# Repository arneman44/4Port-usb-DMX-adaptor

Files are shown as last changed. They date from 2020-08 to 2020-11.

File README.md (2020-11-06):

4Port usb DMX adaptor

As a beginning lighting tech at my local youth club. I needed a cheap way to control some lighting fixtures via DMX. That's why I created this USB-DMX dongle that's open-source so my fellow DIYers can build one themself. I will be selling these as PCB's, kits, and assembled units. At what I find a very reasonable price.

More info can be found on: https://nortle.be/15-diy-4-port-usb-dmx/

i used JCLPCB for ordering pcb's:
https://jlcpcb.com/

<p xmlns:dct="http://purl.org/dc/terms/" xmlns:cc="http://creativecommons.org/ns#" class="license-text"><span rel="dct:title">4 Port USB to DMX adaptor</span> by <a rel="cc:attributionURL dct:creator" property="cc:attributionName" href="www.nortle.be">Arne Van den Broeck</a> is licensed under <a rel="license" href="https://creativecommons.org/licenses/by-nc-sa/4.0">CC BY-NC-SA 4.0</a></p>

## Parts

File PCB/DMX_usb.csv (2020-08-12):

Source: | Y:\Projects\15_PC_DMX_USB_4port\4Port usb DMX adaptor\PCB\DMX_usb.sch
Date: | 5/08/2020 21:19:08
Tool: | Eeschema (5.1.4)-1
Component Count: | 80
Ref | Value | Footprint | Datasheet | Manufacturer | Vendor
C1 | 10uf | Capacitor_SMD:C_0805_2012Metric_Pad1.15x1.40mm_HandSolder | ~
C2 | 10uf | Capacitor_SMD:C_0805_2012Metric_Pad1.15x1.40mm_HandSolder | ~
C3 | 100nf | Capacitor_SMD:C_0805_2012Metric_Pad1.15x1.40mm_HandSolder | ~
C4 | 10uf | Capacitor_SMD:C_0805_2012Metric_Pad1.15x1.40mm_HandSolder | ~
C5 | 4.7uF | Capacitor_SMD:CP_Elec_4x5.4 | ~
C6 | 100nf | Capacitor_SMD:C_0805_2012Metric_Pad1.15x1.40mm_HandSolder | ~
C7 | 100nf | Capacitor_SMD:C_0805_2012Metric_Pad1.15x1.40mm_HandSolder | ~
C8 | 100nf | Capacitor_SMD:C_0805_2012Metric_Pad1.15x1.40mm_HandSolder | ~
C9 | 100nf | Capacitor_SMD:C_0805_2012Metric_Pad1.15x1.40mm_HandSolder | ~
C10 | 4.7uF | Capacitor_SMD:CP_Elec_4x5.4 | ~
C11 | 4.7uF | Capacitor_SMD:CP_Elec_4x5.4 | ~
C12 | 4.7uF | Capacitor_SMD:CP_Elec_4x5.4 | ~
C13 | 100nf | Capacitor_SMD:C_0805_2012Metric_Pad1.15x1.40mm_HandSolder | ~
C14 | 100nf | Capacitor_SMD:C_0805_2012Metric_Pad1.15x1.40mm_HandSolder | ~
C15 | 100nf | Capacitor_SMD:C_0805_2012Metric_Pad1.15x1.40mm_HandSolder | ~
C16 | 10nf | Capacitor_SMD:C_0805_2012Metric_Pad1.15x1.40mm_HandSolder | ~
C17 | 10nf | Capacitor_SMD:C_0805_2012Metric_Pad1.15x1.40mm_HandSolder | ~
C18 | 10nf | Capacitor_SMD:C_0805_2012Metric_Pad1.15x1.40mm_HandSolder | ~
C19 | 10nf | Capacitor_SMD:C_0805_2012Metric_Pad1.15x1.40mm_HandSolder | ~
C20 | 100nf | Capacitor_SMD:C_0805_2012Metric_Pad1.15x1.40mm_HandSolder | ~
C21 | 100nf | Capacitor_SMD:C_0805_2012Metric_Pad1.15x1.40mm_HandSolder | ~
C22 | 100nf | Capacitor_SMD:C_0805_2012Metric_Pad1.15x1.40mm_HandSolder | ~
C23 | 100nf | Capacitor_SMD:C_0805_2012Metric_Pad1.15x1.40mm_HandSolder | ~
C24 | 100nf | Capacitor_SMD:C_0805_2012Metric_Pad1.15x1.40mm_HandSolder | ~
D1 | LED | LED_SMD:LED_0805_2012Metric_Pad1.15x1.40mm_HandSolder | ~
D2 | LED | LED_SMD:LED_0805_2012Metric_Pad1.15x1.40mm_HandSolder | ~
D3 | LED | LED_SMD:LED_0805_2012Metric_Pad1.15x1.40mm_HandSolder | ~
D4 | LED | LED_SMD:LED_0805_2012Metric_Pad1.15x1.40mm_HandSolder | ~
D5 | LED | LED_SMD:LED_0805_2012Metric_Pad1.15x1.40mm_HandSolder | ~
D6 | LED | LED_SMD:LED_0805_2012Metric_Pad1.15x1.40mm_HandSolder | ~
D7 | LED | LED_SMD:LED_0805_2012Metric_Pad1.15x1.40mm_HandSolder | ~
D8 | LED | LED_SMD:LED_0805_2012Metric_Pad1.15x1.40mm_HandSolder | ~
F1 | Polyfuse | Fuse:Fuse_1206_3216Metric_Pad1.42x1.75mm_HandSolder | ~
F2 | Polyfuse | Fuse:Fuse_1206_3216Metric_Pad1.42x1.75mm_HandSolder | ~
F3 | Polyfuse | Fuse:Fuse_1206_3216Metric_Pad1.42x1.75mm_HandSolder | ~
F4 | Polyfuse | Fuse:Fuse_1206_3216Metric_Pad1.42x1.75mm_HandSolder | ~
IC1 | FE1.1S | SamacSys_Parts:SOP64P600X175-28N | https://cdn-shop.adafruit.com/product-files/2991/FE1.1s+Data+Sheet+(Rev.+1.0).pdf
J3 | XLR3 | Connector_Audio:Jack_XLR_Neutrik_NC3FAH1_Horizontal | ~
J4 | XLR3 | Connector_Audio:Jack_XLR_Neutrik_NC3FAH1_Horizontal | ~
J5 | XLR3 | Connector_Audio:Jack_XLR_Neutrik_NC3FAH1_Horizontal | ~
J6 | XLR3 | Connector_Audio:Jack_XLR_Neutrik_NC3FAH1_Horizontal | ~
J9 | Conn_01x03 | Connector_PinSocket_2.54mm:PinSocket_1x03_P2.54mm_Vertical | ~
J10 | Conn_01x03 | Connector_PinSocket_2.54mm:PinSocket_1x03_P2.54mm_Vertical | ~
J11 | Conn_01x03 | Connector_PinSocket_2.54mm:PinSocket_1x03_P2.54mm_Vertical | ~
J12 | Conn_01x03 | Connector_PinSocket_2.54mm:PinSocket_1x03_P2.54mm_Vertical | ~
J13 | USB_C_Receptacle_USB2.0 | Connector_USB:USB_C_Receptacle_Palconn_UTC16-G | https://www.usb.org/sites/default/files/documents/usb_type-c.zip
J14 | USB_C_Receptacle_USB2.0 | Connector_USB:USB_C_Receptacle_Palconn_UTC16-G | https://www.usb.org/sites/default/files/documents/usb_type-c.zip
J15 | USB_C_Receptacle_USB2.0 | Connector_USB:USB_C_Receptacle_Palconn_UTC16-G | https://www.usb.org/sites/default/files/documents/usb_type-c.zip
J16 | USB_C_Receptacle_USB2.0 | Connector_USB:USB_C_Receptacle_Palconn_UTC16-G | https://www.usb.org/sites/default/files/documents/usb_type-c.zip
J17 | Conn_01x04 | Connector_PinSocket_2.54mm:PinSocket_1x04_P2.54mm_Vertical | ~
R1 | 2.7K | Capacitor_SMD:C_0805_2012Metric_Pad1.15x1.40mm_HandSolder | ~
R2 | R | Resistor_SMD:R_0805_2012Metric_Pad1.15x1.40mm_HandSolder | ~
R3 | 560 | Capacitor_SMD:C_0805_2012Metric_Pad1.15x1.40mm_HandSolder | ~
R4 | 130 | Capacitor_SMD:C_0805_2012Metric_Pad1.15x1.40mm_HandSolder | ~
R5 | 560 | Capacitor_SMD:C_0805_2012Metric_Pad1.15x1.40mm_HandSolder | ~
R6 | R | Resistor_SMD:R_0805_2012Metric_Pad1.15x1.40mm_HandSolder | ~
R7 | R | Resistor_SMD:R_0805_2012Metric_Pad1.15x1.40mm_HandSolder | ~
R8 | R | Resistor_SMD:R_0805_2012Metric_Pad1.15x1.40mm_HandSolder | ~
R9 | 560 | Capacitor_SMD:C_0805_2012Metric_Pad1.15x1.40mm_HandSolder | ~
R10 | 130 | Capacitor_SMD:C_0805_2012Metric_Pad1.15x1.40mm_HandSolder | ~
R11 | 560 | Capacitor_SMD:C_0805_2012Metric_Pad1.15x1.40mm_HandSolder | ~
R12 | 560 | Capacitor_SMD:C_0805_2012Metric_Pad1.15x1.40mm_HandSolder | ~
R13 | 130 | Capacitor_SMD:C_0805_2012Metric_Pad1.15x1.40mm_HandSolder | ~
R14 | 560 | Capacitor_SMD:C_0805_2012Metric_Pad1.15x1.40mm_HandSolder | ~
R15 | 560 | Capacitor_SMD:C_0805_2012Metric_Pad1.15x1.40mm_HandSolder | ~
R16 | 130 | Capacitor_SMD:C_0805_2012Metric_Pad1.15x1.40mm_HandSolder | ~
R17 | 560 | Capacitor_SMD:C_0805_2012Metric_Pad1.15x1.40mm_HandSolder | ~
R18 | R | Resistor_SMD:R_0805_2012Metric_Pad1.15x1.40mm_HandSolder | ~
R19 | R | Resistor_SMD:R_0805_2012Metric_Pad1.15x1.40mm_HandSolder | ~
R20 | R | Resistor_SMD:R_0805_2012Metric_Pad1.15x1.40mm_HandSolder | ~
R21 | R | Resistor_SMD:R_0805_2012Metric_Pad1.15x1.40mm_HandSolder | ~
U1 | FT232RL | Package_SO:SSOP-28_5.3x10.2mm_P0.65mm | https://www.ftdichip.com/Support/Documents/DataSheets/ICs/DS_FT232R.pdf
U2 | 75176B | Package_SO:SOIC-8_3.9x4.9mm_P1.27mm
U3 | FT232RL | Package_SO:SSOP-28_5.3x10.2mm_P0.65mm | https://www.ftdichip.com/Support/Documents/DataSheets/ICs/DS_FT232R.pdf
U4 | FT232RL | Package_SO:SSOP-28_5.3x10.2mm_P0.65mm | https://www.ftdichip.com/Support/Documents/DataSheets/ICs/DS_FT232R.pdf
U5 | FT232RL | Package_SO:SSOP-28_5.3x10.2mm_P0.65mm | https://www.ftdichip.com/Support/Documents/DataSheets/ICs/DS_FT232R.pdf
U6 | 75176B | Package_SO:SOIC-8_3.9x4.9mm_P1.27mm
U7 | 75176B | Package_SO:SOIC-8_3.9x4.9mm_P1.27mm
U8 | 75176B | Package_SO:SOIC-8_3.9x4.9mm_P1.27mm
Y1 | Crystal 12MHZ | Crystal:Crystal_SMD_HC49-SD | ~

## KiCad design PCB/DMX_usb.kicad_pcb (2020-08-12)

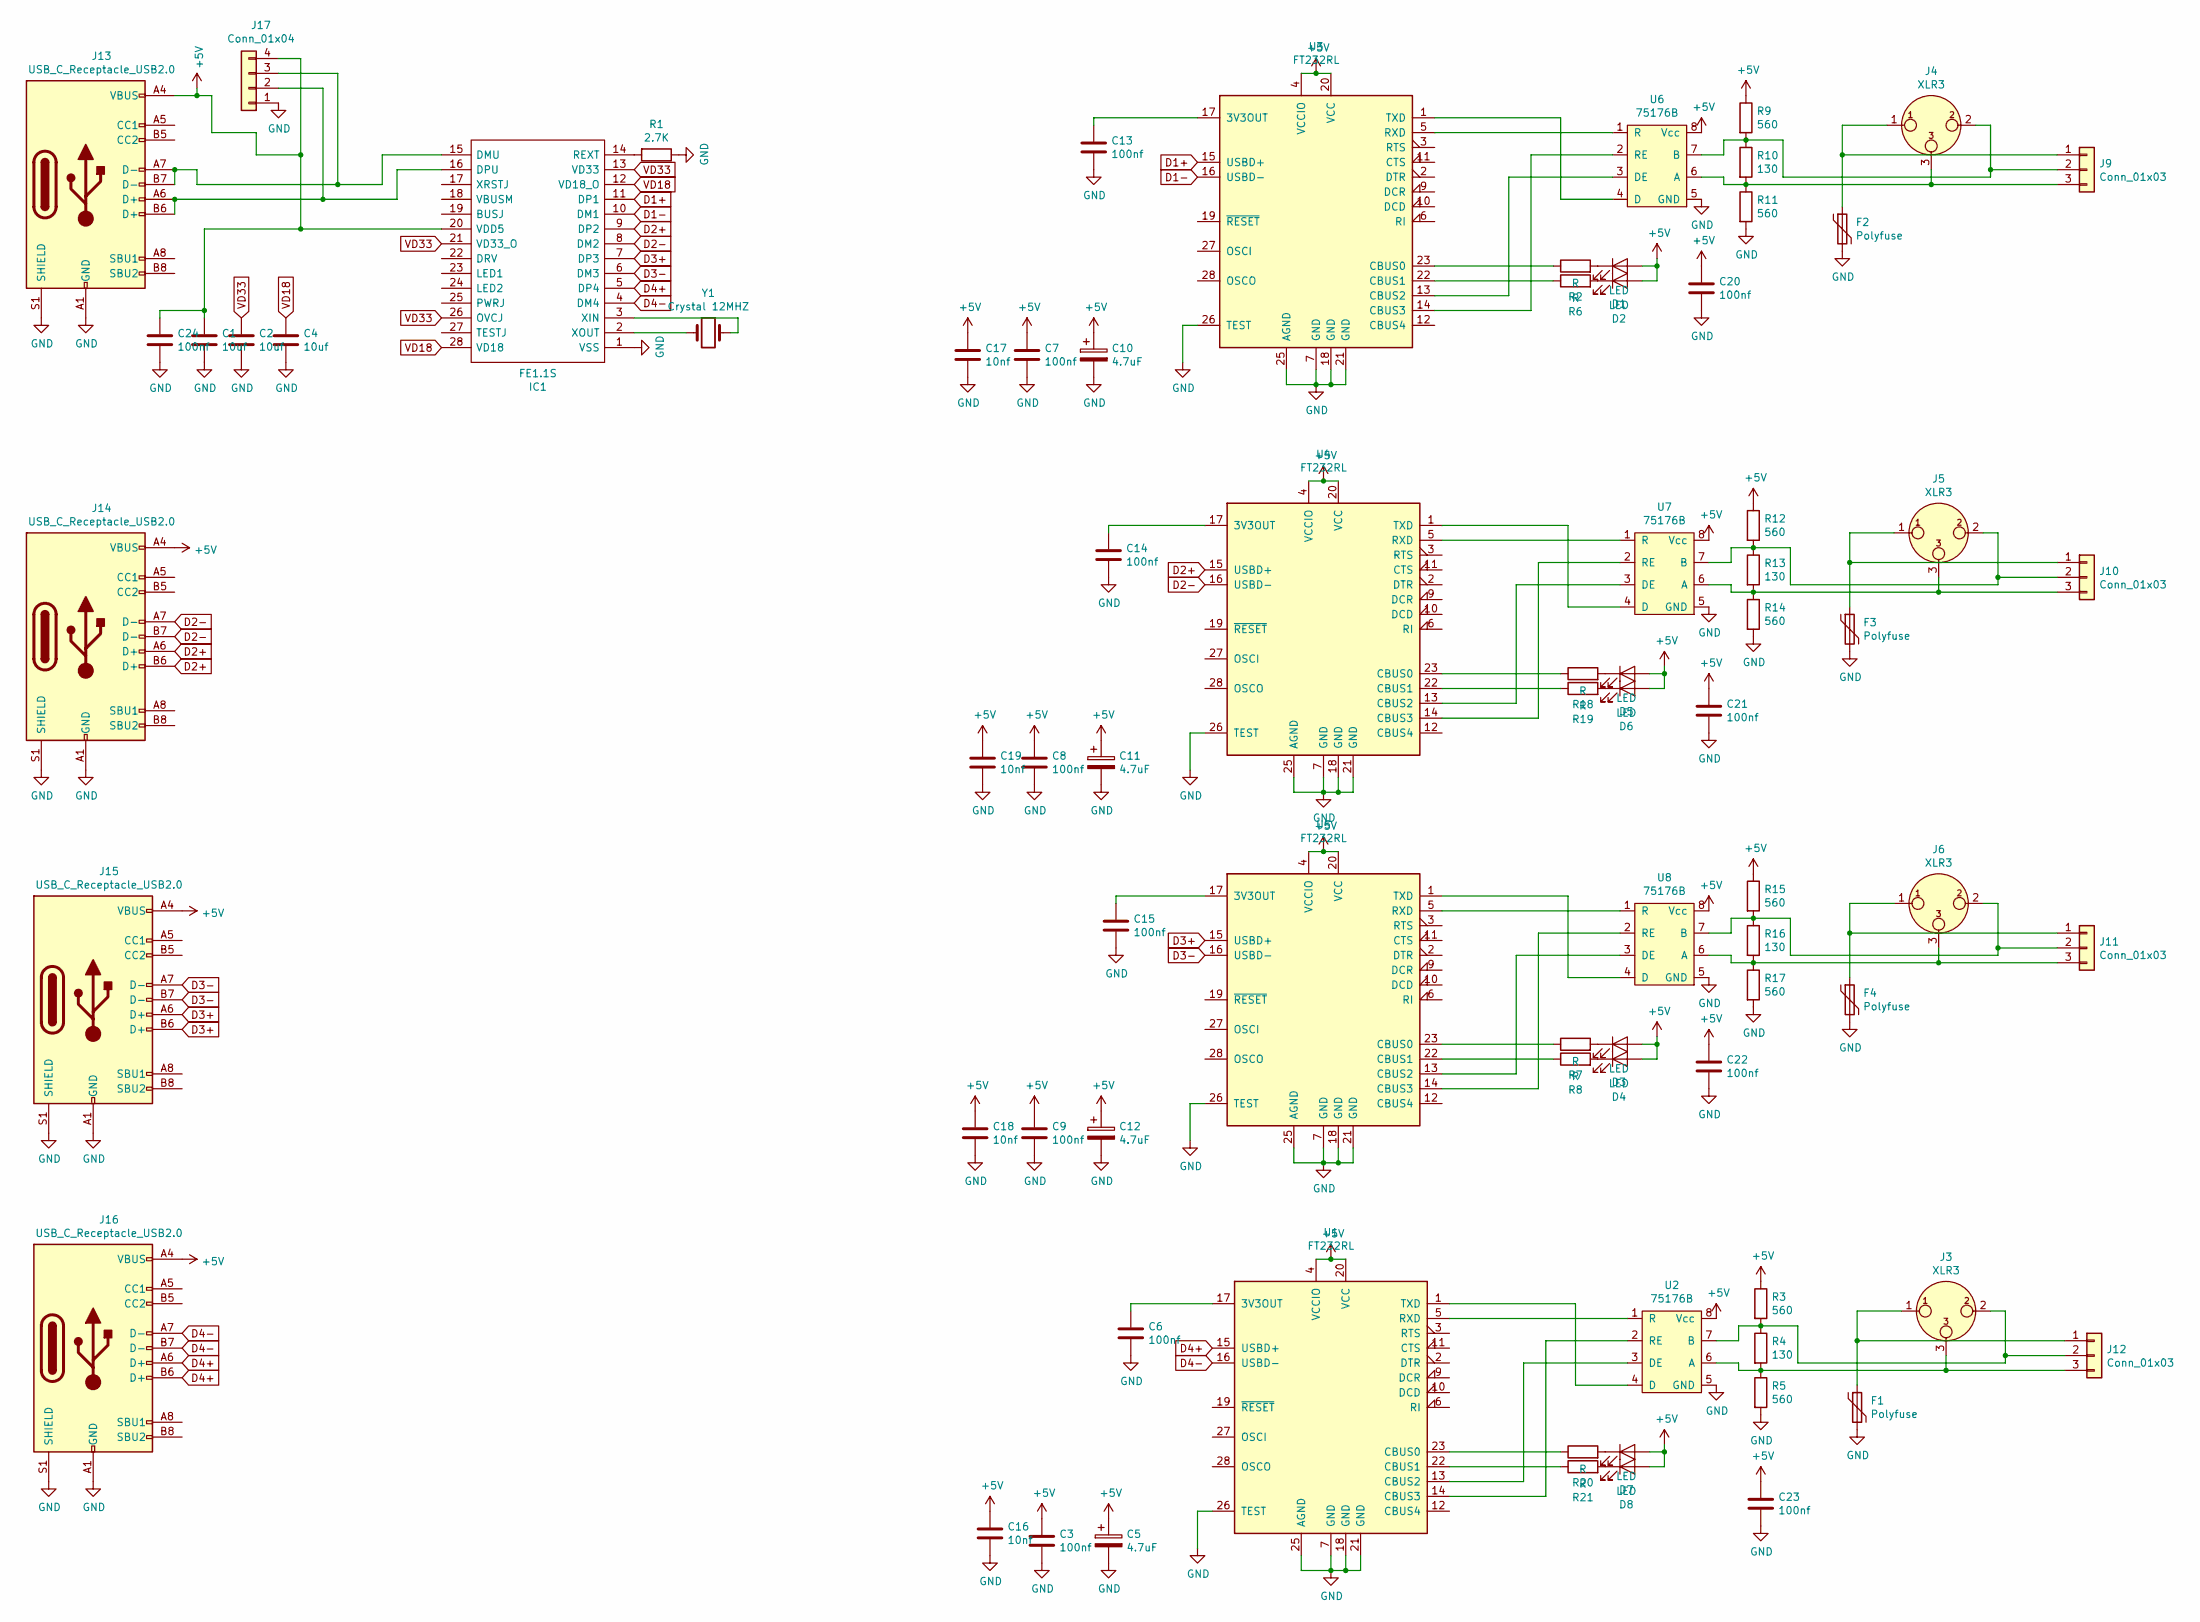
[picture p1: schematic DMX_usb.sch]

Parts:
C1, C2, C4: 10uf; C_0805_2012Metric_Pad1.15x1.40mm_HandSolder
C3, C6, C7, C8, C9, C13, C14, C15, C20, C21, C22, C23, C24: 100nf; C_0805_2012Metric_Pad1.15x1.40mm_HandSolder
C5, C10, C11, C12: 4.7uF; CP_Elec_4x5.4
C16, C17, C18, C19: 10nf; C_0805_2012Metric_Pad1.15x1.40mm_HandSolder
D1, D2, D3, D4, D5, D6, D7, D8: LED; LED_0805_2012Metric_Pad1.15x1.40mm_HandSolder
F1, F2, F3, F4: Polyfuse; Fuse_1206_3216Metric_Pad1.42x1.75mm_HandSolder
IC1: FE1.1S; SOP64P600X175-28N; Manufacturer_Part_Number FE1.1S
J3, J4, J5, J6: XLR3; Jack_XLR_Neutrik_NC3FAH1_Horizontal
J9, J10, J11, J12: Conn_01x03; PinSocket_1x03_P2.54mm_Vertical
J13, J14, J15, J16: USB_C_Receptacle_USB2.0; USB_C_Receptacle_Palconn_UTC16-G
J17: Conn_01x04; PinSocket_1x04_P2.54mm_Vertical
R1: 2.7K; C_0805_2012Metric_Pad1.15x1.40mm_HandSolder
R2, R6, R7, R8, R18, R19, R20, R21: R; R_0805_2012Metric_Pad1.15x1.40mm_HandSolder
R3, R5, R9, R11, R12, R14, R15, R17: 560; C_0805_2012Metric_Pad1.15x1.40mm_HandSolder
R4, R10, R13, R16: 130; C_0805_2012Metric_Pad1.15x1.40mm_HandSolder
U1, U3, U4, U5: FT232RL; SSOP-28_5.3x10.2mm_P0.65mm
U2, U6, U7, U8: 75176B; SOIC-8_3.9x4.9mm_P1.27mm
Y1: Crystal 12MHZ; Crystal_SMD_HC49-SD

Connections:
+5V: C1.1, C3.1, C5.1, C7.1, C8.1, C9.1, C10.1, C11.1, C12.1, C16.1, C17.1, C18.1, C19.1, C20.1, C21.1, C22.1, C23.1, C24.1, D1.2 (A), D2.2 (A), D3.2 (A), D4.2 (A), D5.2 (A), D6.2 (A), D7.2 (A), D8.2 (A), IC1.20 (VDD5), J13.A4 (VBUS), J13.A9 (VBUS), J13.B4 (VBUS), J13.B9 (VBUS), J14.A4 (VBUS), J14.A9 (VBUS), J14.B4 (VBUS), J14.B9 (VBUS), J15.A4 (VBUS), J15.A9 (VBUS), J15.B4 (VBUS), J15.B9 (VBUS), J16.A4 (VBUS), J16.A9 (VBUS), J16.B4 (VBUS), J16.B9 (VBUS), J17.4, R3.1, R9.1, R12.1, R15.1, U1.4 (VCCIO), U1.20 (VCC), U2.8 (Vcc), U3.4 (VCCIO), U3.20 (VCC), U4.4 (VCCIO), U4.20 (VCC), U5.4 (VCCIO), U5.20 (VCC), U6.8 (Vcc), U7.8 (Vcc), U8.8 (Vcc)
D1+: IC1.11 (DP1), U3.15 (USBD+)
D1-: IC1.10 (DM1), U3.16 (USBD-)
D2+: IC1.9 (DP2), J14.A6 (D+), J14.B6 (D+), U4.15 (USBD+)
D2-: IC1.8 (DM2), J14.A7 (D-), J14.B7 (D-), U4.16 (USBD-)
D3+: IC1.7 (DP3), J15.A6 (D+), J15.B6 (D+), U5.15 (USBD+)
D3-: IC1.6 (DM3), J15.A7 (D-), J15.B7 (D-), U5.16 (USBD-)
D4+: IC1.5 (DP4), J16.A6 (D+), J16.B6 (D+), U1.15 (USBD+)
D4-: IC1.4 (DM4), J16.A7 (D-), J16.B7 (D-), U1.16 (USBD-)
GND: C1.2, C2.2, C3.2, C4.2, C5.2, C6.2, C7.2, C8.2, C9.2, C10.2, C11.2, C12.2, C13.2, C14.2, C15.2, C16.2, C17.2, C18.2, C19.2, C20.2, C21.2, C22.2, C23.2, C24.2, F1.2, F2.2, F3.2, F4.2, IC1.1 (VSS), J13.A1 (GND), J13.A12 (GND), J13.B1 (GND), J13.B12 (GND), J13.S1 (SHIELD), J14.A1 (GND), J14.A12 (GND), J14.B1 (GND), J14.B12 (GND), J14.S1 (SHIELD), J15.A1 (GND), J15.A12 (GND), J15.B1 (GND), J15.B12 (GND), J15.S1 (SHIELD), J16.A1 (GND), J16.A12 (GND), J16.B1 (GND), J16.B12 (GND), J16.S1 (SHIELD), J17.1, R1.1, R5.2, R11.2, R14.2, R17.2, U1.7 (GND), U1.18 (GND), U1.21 (GND), U1.25 (AGND), U1.26 (TEST), U2.5 (GND), U3.7 (GND), U3.18 (GND), U3.21 (GND), U3.25 (AGND), U3.26 (TEST), U4.7 (GND), U4.18 (GND), U4.21 (GND), U4.25 (AGND), U4.26 (TEST), U5.7 (GND), U5.18 (GND), U5.21 (GND), U5.25 (AGND), U5.26 (TEST), U6.5 (GND), U7.5 (GND), U8.5 (GND)
unnamed: C6.1, U1.17 (3V3OUT)
unnamed: C13.1, U3.17 (3V3OUT)
unnamed: C14.1, U4.17 (3V3OUT)
unnamed: C15.1, U5.17 (3V3OUT)
unnamed: D1.1 (K), R2.2
unnamed: D2.1 (K), R6.2
unnamed: D3.1 (K), R7.2
unnamed: D4.1 (K), R8.2
unnamed: D5.1 (K), R18.2
unnamed: D6.1 (K), R19.2
unnamed: D7.1 (K), R20.2
unnamed: D8.1 (K), R21.2
unnamed: F1.1, J3.1, J12.1
unnamed: F2.1, J4.1, J9.1
unnamed: F3.1, J5.1, J10.1
unnamed: F4.1, J6.1, J11.1
unnamed: IC1.2 (XOUT), Y1.1
unnamed: IC1.3 (XIN), Y1.2
unnamed: IC1.14 (REXT), R1.2
unnamed: IC1.15 (DMU), J13.A7 (D-), J13.B7 (D-), J17.3
unnamed: IC1.16 (DPU), J13.A6 (D+), J13.B6 (D+), J17.2
unnamed: J4.2, J9.2, R9.2, R10.1, U6.7 (B)
unnamed: J4.3, J9.3, R10.2, R11.1, U6.6 (A)
unnamed: J5.2, J10.2, R12.2, R13.1, U7.7 (B)
unnamed: J5.3, J10.3, R13.2, R14.1, U7.6 (A)
unnamed: J6.2, J11.2, R15.2, R16.1, U8.7 (B)
unnamed: J6.3, J11.3, R16.2, R17.1, U8.6 (A)
unnamed: J3.2, J12.2, R3.2, R4.1, U2.7 (B)
unnamed: J3.3, J12.3, R4.2, R5.1, U2.6 (A)
unnamed: R2.1, U3.23 (CBUS0)
unnamed: R6.1, U3.22 (CBUS1)
unnamed: R7.1, U5.23 (CBUS0)
unnamed: R8.1, U5.22 (CBUS1)
unnamed: R18.1, U4.23 (CBUS0)
unnamed: R19.1, U4.22 (CBUS1)
unnamed: R20.1, U1.23 (CBUS0)
unnamed: R21.1, U1.22 (CBUS1)
unnamed: U1.1 (TXD), U2.4 (D)
unnamed: U1.5 (RXD), U2.1 (R)
unnamed: U1.13 (CBUS2), U2.3 (DE)
unnamed: U1.14 (CBUS3), U2.2 (RE)
unnamed: U3.1 (TXD), U6.4 (D)
unnamed: U3.5 (RXD), U6.1 (R)
unnamed: U3.13 (CBUS2), U6.3 (DE)
unnamed: U3.14 (CBUS3), U6.2 (RE)
unnamed: U4.1 (TXD), U7.4 (D)
unnamed: U4.5 (RXD), U7.1 (R)
unnamed: U4.13 (CBUS2), U7.3 (DE)
unnamed: U4.14 (CBUS3), U7.2 (RE)
unnamed: U5.1 (TXD), U8.4 (D)
unnamed: U5.5 (RXD), U8.1 (R)
unnamed: U5.13 (CBUS2), U8.3 (DE)
unnamed: U5.14 (CBUS3), U8.2 (RE)
VD18: C4.1, IC1.12 (VD18_O), IC1.28 (VD18)
VD33: C2.1, IC1.13 (VD33), IC1.21 (VD33_O), IC1.26 (OVCJ)

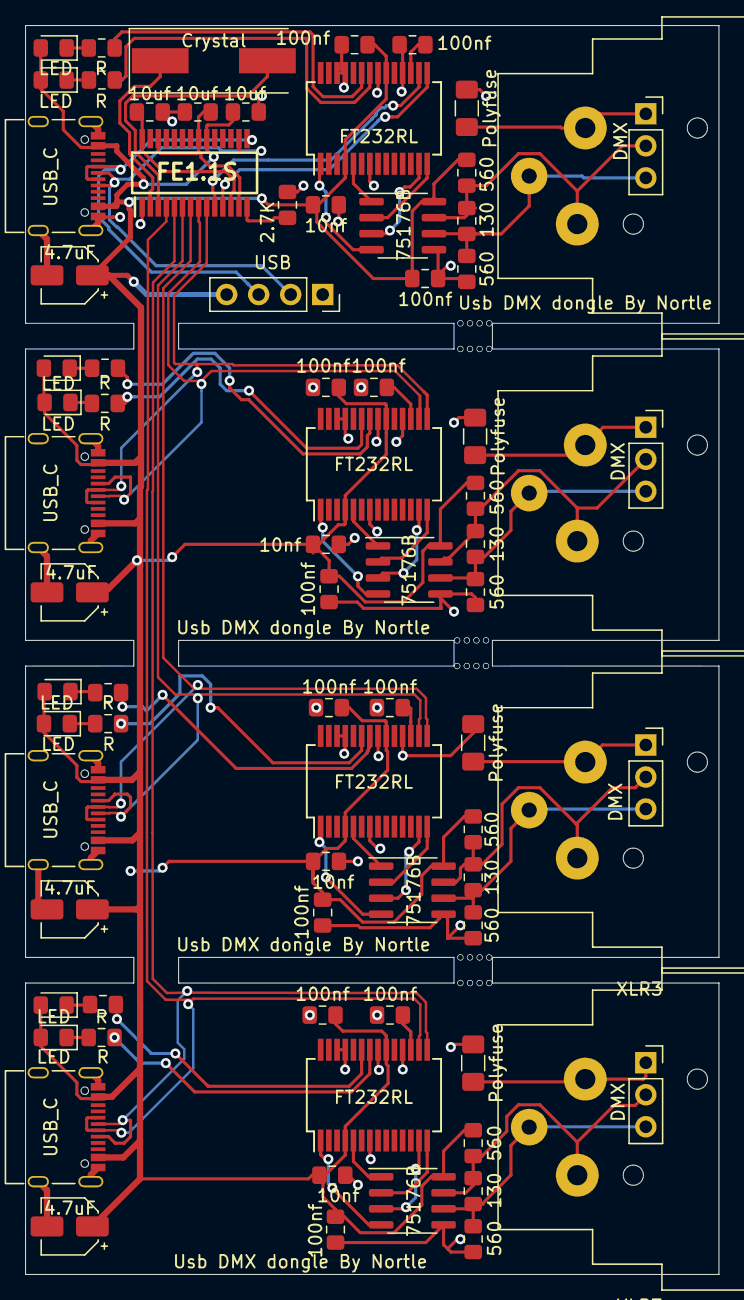
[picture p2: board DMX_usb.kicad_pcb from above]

Board: 2 copper layers, 55.0 x 99.1 mm, 79 parts (0 on the bottom side), 65 nets.

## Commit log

2020-06-25 add PCB files
    V1 PCB
    [DMX_usb.kicad_pcb, DMX_usb.sch]
2020-06-25 restructure PCB files
    [DMX_usb.kicad_pcb, DMX_usb.sch]
2020-07-11 V1 version
    [DMX_usb-B_Cu.gbr, DMX_usb-B_Mask.gbr, DMX_usb-B_Paste.gbr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]
2020-08-12 v2
    fixed some stupid problems with pcb desgn
    [DMX_usb-B_Cu.gbr, DMX_usb-B_Mask.gbr, DMX_usb-B_Paste.gbr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]
